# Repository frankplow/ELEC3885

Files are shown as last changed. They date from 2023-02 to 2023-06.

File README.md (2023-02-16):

# A robust and lightweight helmet-mounted safety camera for cycling
ELEC3885: Group Design Project, group 4 project at the University of Leeds.

The objective of this project is to design and produce a prototype for a camera to mount to the helmet of a cyclist, as well as a software suite for the analysis of footage and user documentation. The camera is intended as a safety device, for example for use in legal proceedings, rather than an 'action cam'. Because of this, it should be low-cost and should not require much effort by the user, for example charging, to use.

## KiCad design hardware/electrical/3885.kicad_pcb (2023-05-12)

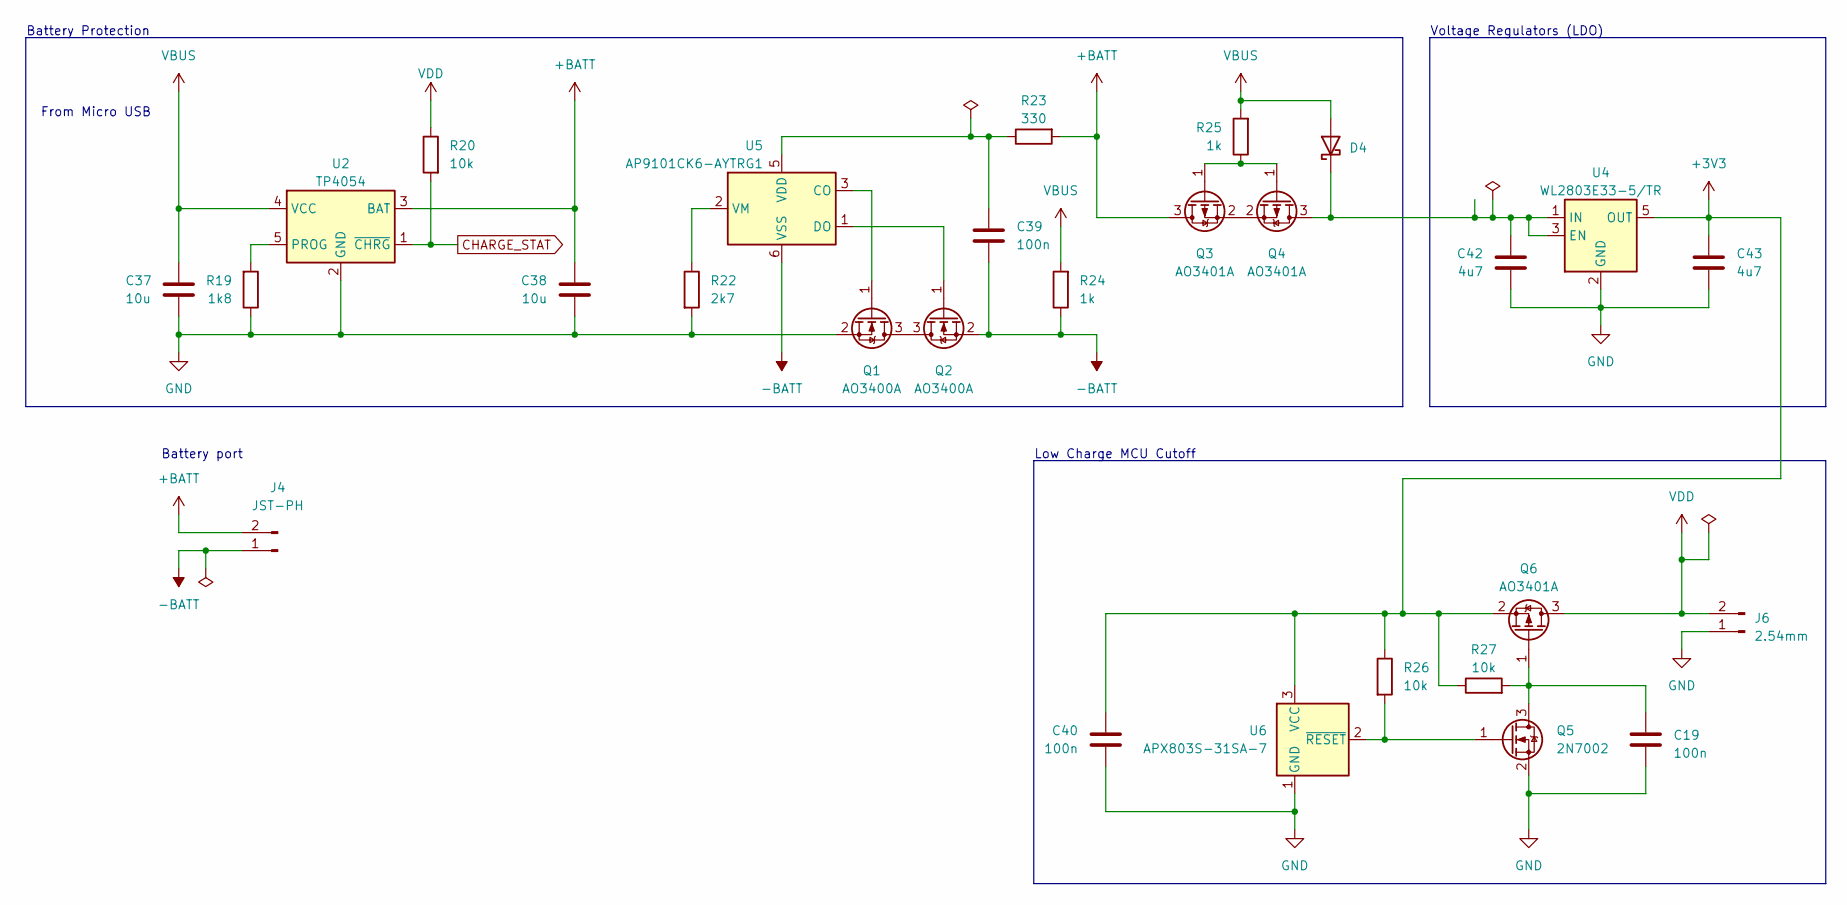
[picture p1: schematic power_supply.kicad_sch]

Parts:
C19, C39, C40: 100n; C_0402_1005Metric; Mfr. Part # CL05B104KO5NNNC; LCSC Part # C1525
C37, C38: 10u; C_0402_1005Metric; Mfr. Part # CL05A106MQ5NUNC; LCSC Part # C15525
C42, C43: 4u7; C_0402_1005Metric; Mfr. Part # CL05A475MP5NRNC; LCSC Part # C23733
D4: D_Schottky; D_SOD-323; Mfr. Part # 1N5819WS; LCSC Part # C191023
J4: JST-PH; JST_PH_S2B-PH-K_1x02_P2.00mm_Horizontal; Mfr. Part # S2B-PH-K-S(LF)(SN); LCSC Part # C173752
J6: 2.54mm; PinHeader_1x02_P2.54mm_Vertical
Q1, Q2: AO3400A; JLC_SOT-23; Mfr. Part # AO3400A; LCSC Part # C20917
Q3, Q4, Q6: AO3401A; JLC_SOT-23; Mfr. Part # AO3401A; LCSC Part # C15127
Q5: 2N7002; JLC_SOT-23; Mfr. Part # 2N7002; LCSC Part # C8545
R19: 1k8; R_0603_1608Metric; Mfr. Part # 0603WAF1801T5E; LCSC Part # C4177
R20, R26, R27: 10k; R_0402_1005Metric; Mfr. Part # 0402WGF1002TCE; LCSC Part # C25744
R22: 2k7; R_0603_1608Metric; Mfr. Part # 0603WAF2701T5E; LCSC Part # C13167
R23: 330; R_0402_1005Metric; Mfr. Part # 0402WGF3300TCE; LCSC Part # C25104
R24, R25: 1k; R_0402_1005Metric; Mfr. Part # 0402WGF1001TCE; LCSC Part # C11702
U2: TP4054; JLC_SOT-23-5; Mfr. Part # TP4054-42-SOT25R; LCSC Part # C32574
U4: WL2803E33-5/TR; JLC_SOT-23-5; Mfr. Part # WL2803E33-5/TR; LCSC Part # C192928
U5: AP9101CK6-AYTRG1; JLC_SOT-23-6; Mfr. Part # AP9101CK6-AYTRG1; LCSC Part # C507889
U6: APX803S-31SA-7; JLC_SOT-23; Mfr. Part # APX803S-31SA-7; LCSC Part # C129757

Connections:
+3V3: C40.1, C43.2, Q6.2 (S), R26.1, R27.1, U4.5 (OUT), U6.3 (VCC); also elsewhere on the board
+BATT: C38.2, J4.2, Q3.3 (D), R23.2, U2.3 (BAT)
-BATT: C39.1, J4.1, Q2.2 (S), R24.1, U5.6 (VSS)
CHARGE_STAT: R20.2, U2.1 (~CHRG); also elsewhere on the board
GND: C19.2, C37.2, C38.1, C40.2, C42.1, C43.1, J6.1, Q1.2 (S), Q5.2 (S), R19.1, R22.2, U2.2 (GND), U4.2 (GND), U6.1 (GND); also elsewhere on the board
unnamed: C42.2, D4.1 (K), Q4.3 (D), U4.1 (IN), U4.3 (EN)
unnamed: Q1.3 (D), Q2.3 (D)
unnamed: Q1.1 (G), U5.3 (CO)
unnamed: Q2.1 (G), U5.1 (DO)
unnamed: Q3.1 (G), Q4.1 (G), R25.1
unnamed: Q3.2 (S), Q4.2 (S)
unnamed: C19.1, Q5.3 (D), Q6.1 (G), R27.2
unnamed: Q5.1 (G), R26.2, U6.2 (~RESET)
unnamed: R19.2, U2.5 (PROG)
unnamed: C39.2, R23.1, U5.5 (VDD)
unnamed: R22.1, U5.2 (VM)
VBUS: C37.1, D4.2 (A), R24.2, R25.2, U2.4 (VCC); also elsewhere on the board
VDD: J6.2, Q6.3 (D), R20.1; also elsewhere on the board

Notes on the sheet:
Voltage Regulators (LDO)
Low Charge MCU Cutoff
From Micro USB
Battery Protection
Battery port

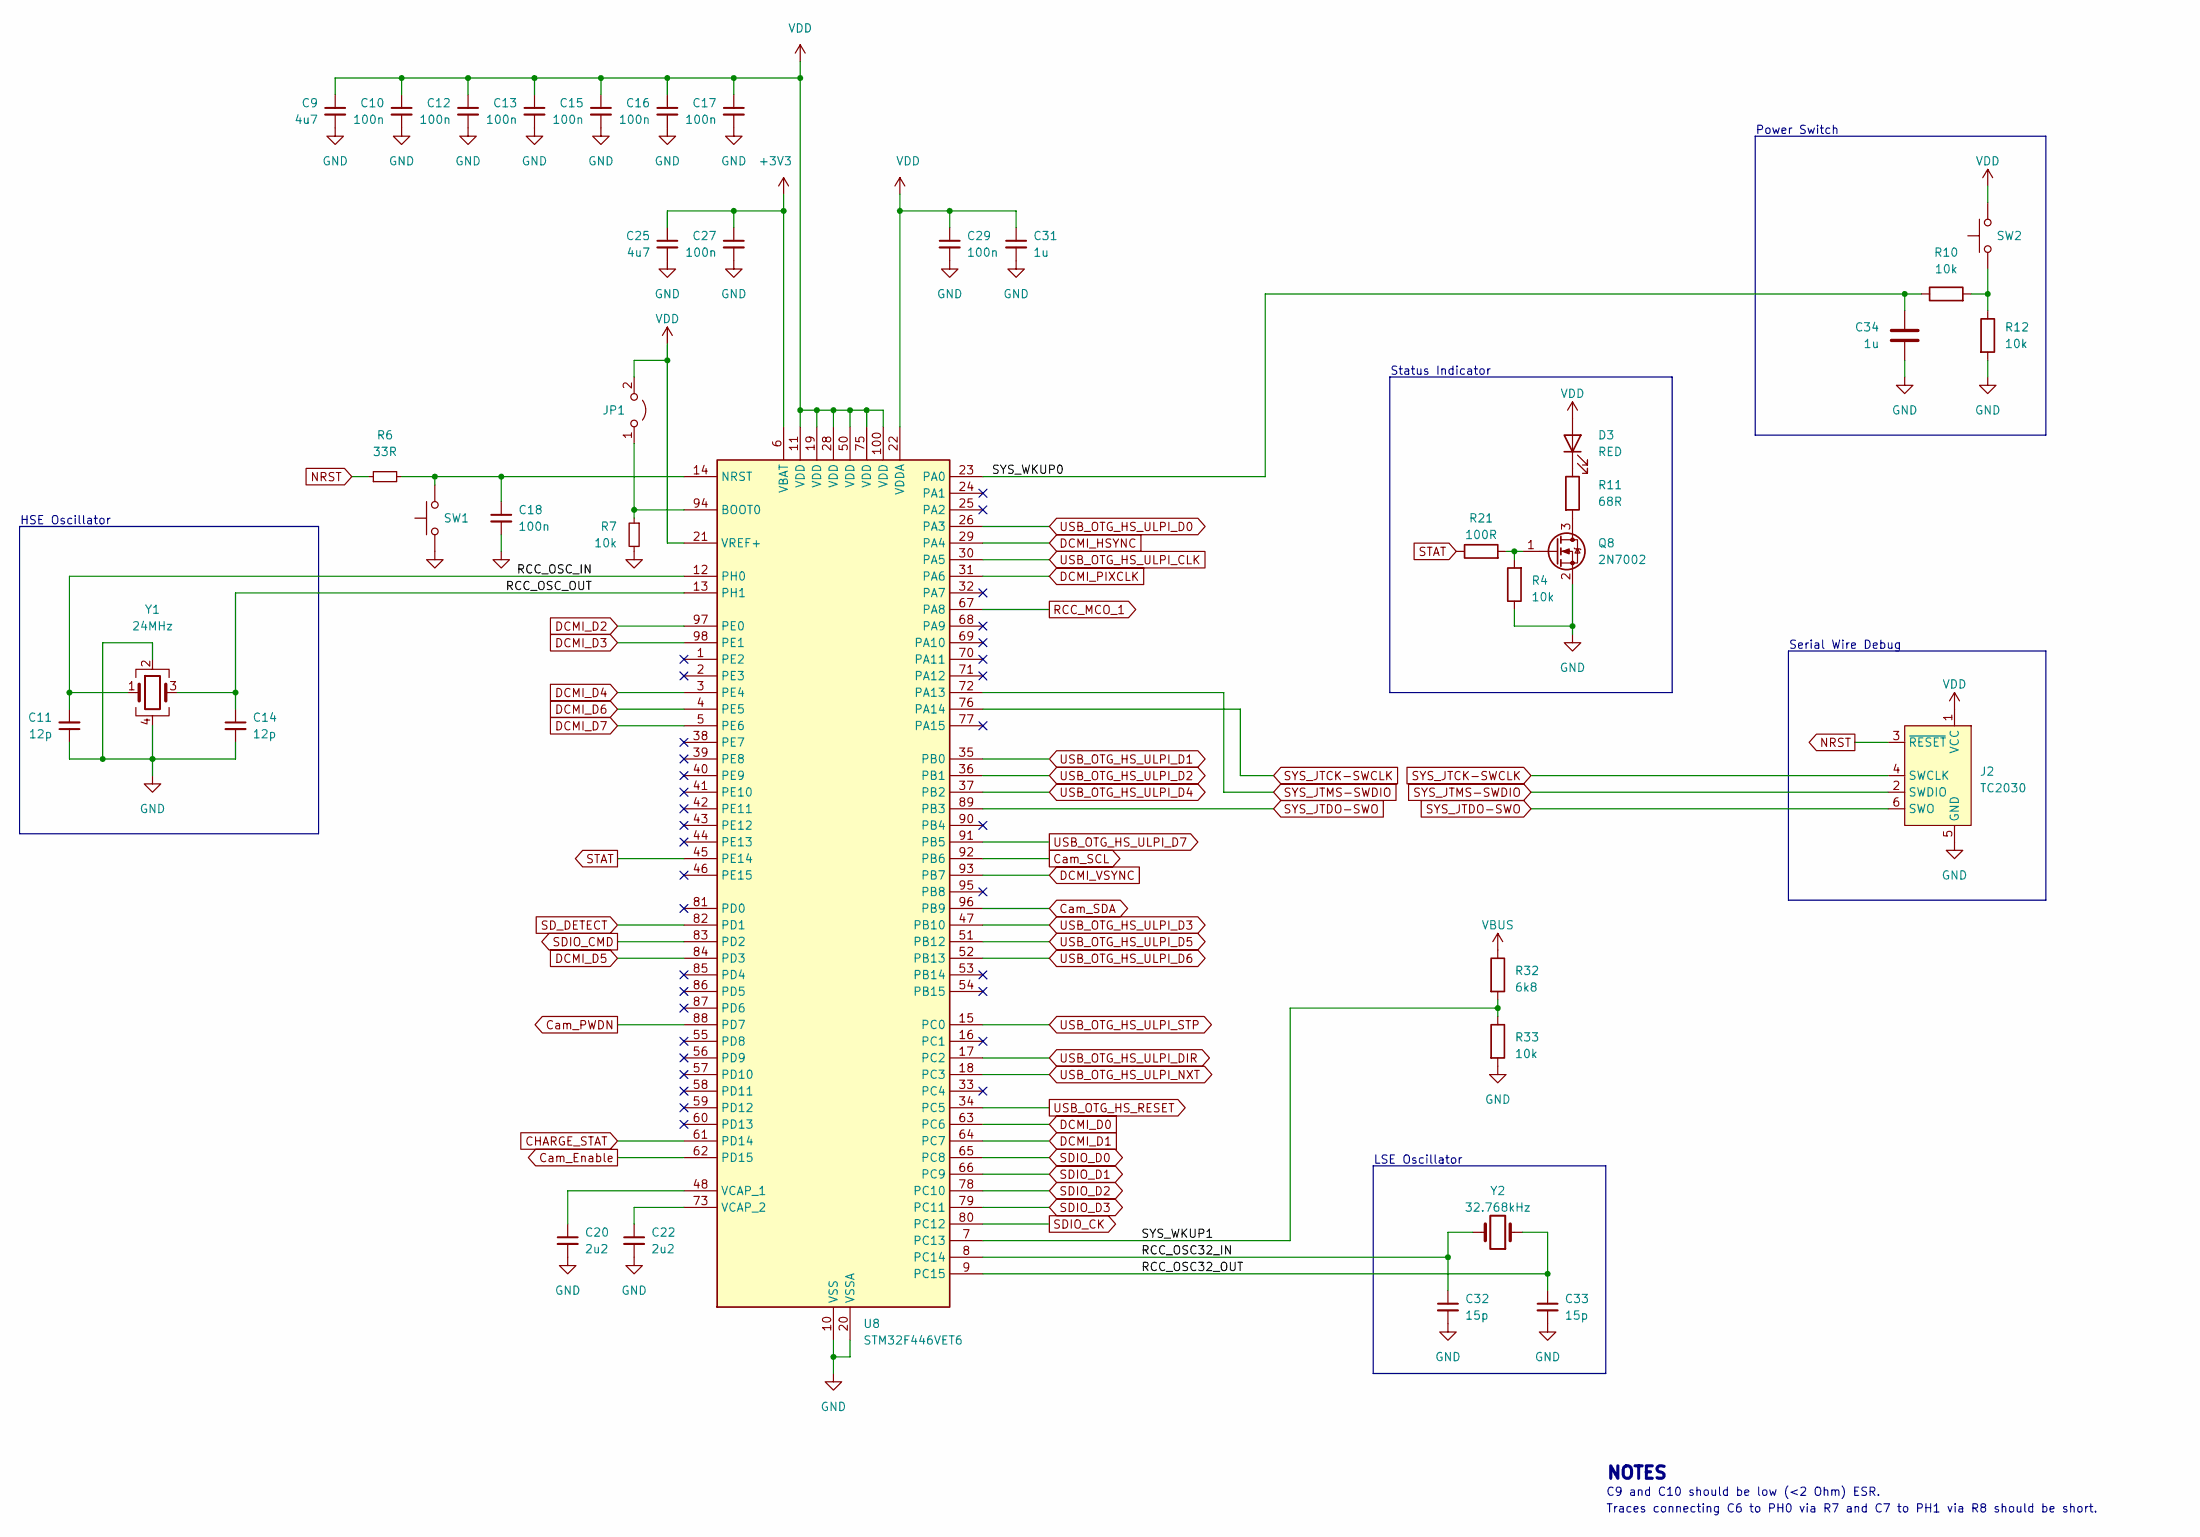
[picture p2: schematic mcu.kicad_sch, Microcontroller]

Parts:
C9, C25: 4u7; C_0402_1005Metric; Mfr. Part # CL05A475MP5NRNC; LCSC Part # C23733
C10, C12, C13, C15, C16, C17, C18, C27, C29: 100n; C_0402_1005Metric; Mfr. Part # CL05B104KO5NNNC; LCSC Part # C1525
C11, C14: 12p; C_0603_1608Metric; Mfr. Part # CL10C120JB8NNNC; LCSC Part # C38523
C20, C22: 2u2; C_0402_1005Metric; Mfr. Part # CL05A225MQ5NSNC; LCSC Part # C12530
C31, C34: 1u; C_0402_1005Metric; Mfr. Part # CL05A105KA5NQNC; LCSC Part # C52923
C32, C33: 15p; C_0603_1608Metric; Mfr. Part # CL10C150JB8NNNC; LCSC Part # C1644
D3: RED; Everlight_21-21S; Mfr. Part # 12-21SURC/S530-A3/TR8; LCSC Part # C131288
J2: TC2030; Tag-Connect_TC2030-IDC-FP_2x03_P1.27mm_Vertical
JP1: Jumper_2_Open; SolderJumper-2_P1.3mm_Open_Pad1.0x1.5mm
Q8: 2N7002; JLC_SOT-23; Mfr. Part # 2N7002; LCSC Part # C8545
R4: 10k; R_0402_1005Metric; Mfr. Part # 0402WGF1000TCE; LCSC Part # C25076
R6: 33R; R_0402_1005Metric; Mfr. Part # 0402WGF330JTCE; LCSC Part # C25105
R7, R10, R12, R33: 10k; R_0402_1005Metric; Mfr. Part # 0402WGF1002TCE; LCSC Part # C25744
R11: 68R; R_0603_1608Metric; Mfr. Part # 0603WAF680JT5E; LCSC Part # C27592
R21: 100R; R_0402_1005Metric; Mfr. Part # 0402WGF1000TCE; LCSC Part # C25076
R32: 6k8; R_0402_1005Metric; Mfr. Part # 0402WGF6801TCE; LCSC Part # C25917
SW1: TS-1187A-B-A-B; SW_SPST_XKB_TS-1187A; Mfr. Part # TS-1187A-B-A-B; LCSC Part # C318884
SW2: GT-TC018B-H0375-L1; G-Switch_GT-TC018; Mfr. Part # GT-TC018B-H0375-L1; LCSC Part # C2762970
U8: STM32F446VET6; JLC_LQFP-100_14x14mm_P0.5mm; Mfr. Part # STM32F446VET6; LCSC Part # C91929
Y1: 24MHz; Crystal_SMD_SeikoEpson_TSX3225-4Pin_3.2x2.5mm; Mfr. Part # X1E0000210129; LCSC Part # C255917
Y2: 32.768kHz; Crystal_SMD_3215-2Pin_3.2x1.5mm; Mfr. Part # Q13FC1350000400; LCSC Part # C32346

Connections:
+3V3: C25.1, C27.1, U8.6 (VBAT); also elsewhere on the board
/Microcontroller/RCC_OSC32_IN: C32.1, U8.8 (PC14), Y2.2
/Microcontroller/RCC_OSC32_OUT: C33.1, U8.9 (PC15), Y2.1
/Microcontroller/RCC_OSC_IN: C11.2, U8.12 (PH0), Y1.1
/Microcontroller/RCC_OSC_OUT: C14.1, U8.13 (PH1), Y1.3
/Microcontroller/SYS_WKUP0: C34.2, R10.1, U8.23 (PA0)
/Microcontroller/SYS_WKUP1: R32.2, R33.1, U8.7 (PC13)
CHARGE_STAT: U8.61 (PD14); also elsewhere on the board
Cam_Enable: U8.62 (PD15); also elsewhere on the board
Cam_PWDN: U8.88 (PD7); also elsewhere on the board
Cam_SCL: U8.92 (PB6); also elsewhere on the board
Cam_SDA: U8.96 (PB9); also elsewhere on the board
DCMI_D0: U8.63 (PC6); also elsewhere on the board
DCMI_D1: U8.64 (PC7); also elsewhere on the board
DCMI_D2: U8.97 (PE0); also elsewhere on the board
DCMI_D3: U8.98 (PE1); also elsewhere on the board
DCMI_D4: U8.3 (PE4); also elsewhere on the board
DCMI_D5: U8.84 (PD3); also elsewhere on the board
DCMI_D6: U8.4 (PE5); also elsewhere on the board
DCMI_D7: U8.5 (PE6); also elsewhere on the board
DCMI_HSYNC: U8.29 (PA4); also elsewhere on the board
DCMI_PIXCLK: U8.31 (PA6); also elsewhere on the board
DCMI_VSYNC: U8.93 (PB7); also elsewhere on the board
GND: C9.2, C10.2, C11.1, C12.2, C13.2, C14.2, C15.2, C16.2, C17.2, C18.2, C20.2, C22.2, C25.2, C27.2, C29.2, C31.2, C32.2, C33.2, C34.1, J2.5 (GND), Q8.2 (S), R4.1, R7.2, R12.2, R33.2, SW1.1, U8.10 (VSS), U8.20 (VSSA), U8.27 (VSS), U8.49 (VSS), U8.74 (VSS), U8.99 (VSS), Y1.2, Y1.4; also elsewhere on the board
NRST: J2.3 (~RESET), R6.1
unnamed: D3.1 (K), R11.1
unnamed: JP1.1 (A), R7.1, U8.94 (BOOT0)
unnamed: Q8.3 (D), R11.2
unnamed: Q8.1 (G), R4.2, R21.2
unnamed: R10.2, R12.1, SW2.1
unnamed: C18.1, R6.2, SW1.2, U8.14 (NRST)
unnamed: C20.1, U8.48 (VCAP_1)
unnamed: C22.1, U8.73 (VCAP_2)
RCC_MCO_1: U8.67 (PA8); also elsewhere on the board
SDIO_CK: U8.80 (PC12); also elsewhere on the board
SDIO_CMD: U8.83 (PD2); also elsewhere on the board
SDIO_D0: U8.65 (PC8); also elsewhere on the board
SDIO_D1: U8.66 (PC9); also elsewhere on the board
SDIO_D2: U8.78 (PC10); also elsewhere on the board
SDIO_D3: U8.79 (PC11); also elsewhere on the board
SD_DETECT: U8.82 (PD1); also elsewhere on the board
STAT: R21.1, U8.45 (PE14)
SYS_JTCK-SWCLK: J2.4 (SWCLK), U8.76 (PA14)
SYS_JTDO-SWO: J2.6 (SWO), U8.89 (PB3)
SYS_JTMS-SWDIO: J2.2 (SWDIO), U8.72 (PA13)
USB_OTG_HS_RESET: U8.34 (PC5); also elsewhere on the board
USB_OTG_HS_ULPI_CLK: U8.30 (PA5); also elsewhere on the board
USB_OTG_HS_ULPI_D0: U8.26 (PA3); also elsewhere on the board
USB_OTG_HS_ULPI_D1: U8.35 (PB0); also elsewhere on the board
USB_OTG_HS_ULPI_D2: U8.36 (PB1); also elsewhere on the board
USB_OTG_HS_ULPI_D3: U8.47 (PB10); also elsewhere on the board
USB_OTG_HS_ULPI_D4: U8.37 (PB2); also elsewhere on the board
USB_OTG_HS_ULPI_D5: U8.51 (PB12); also elsewhere on the board
USB_OTG_HS_ULPI_D6: U8.52 (PB13); also elsewhere on the board
USB_OTG_HS_ULPI_D7: U8.91 (PB5); also elsewhere on the board
USB_OTG_HS_ULPI_DIR: U8.17 (PC2); also elsewhere on the board
USB_OTG_HS_ULPI_NXT: U8.18 (PC3); also elsewhere on the board
USB_OTG_HS_ULPI_STP: U8.15 (PC0); also elsewhere on the board
VBUS: R32.1; also elsewhere on the board
VDD: C9.1, C10.1, C12.1, C13.1, C15.1, C16.1, C17.1, C29.1, C31.1, D3.2 (A), J2.1 (VCC), JP1.2 (B), SW2.2, U8.11 (VDD), U8.19 (VDD), U8.21 (VREF+), U8.22 (VDDA), U8.28 (VDD), U8.50 (VDD), U8.75 (VDD), U8.100 (VDD); also elsewhere on the board

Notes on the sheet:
C9 and C10 should be low (<2 Ohm) ESR.
Traces connecting C6 to PH0 via R7 and C7 to PH1 via R8 should be short.
LSE Oscillator
Serial Wire Debug
HSE Oscillator
Status Indicator
NOTES
Power Switch

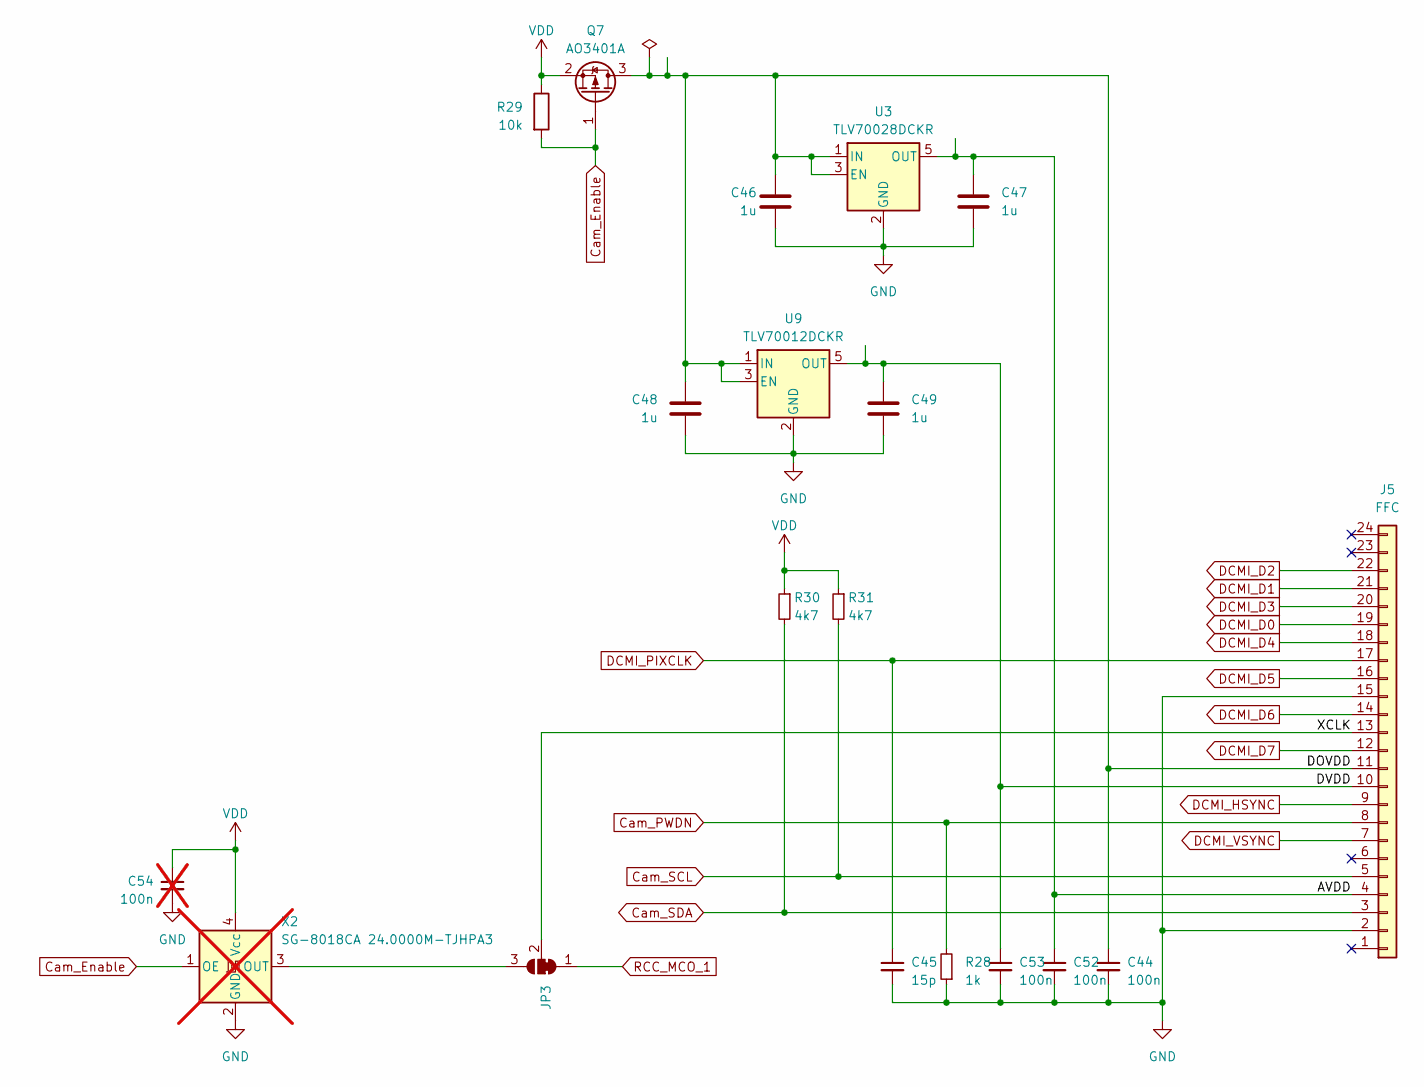
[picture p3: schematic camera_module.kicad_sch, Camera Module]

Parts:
C44, C52, C53: 100n; C_0402_1005Metric; Mfr. Part # CL05B104KO5NNNC; LCSC Part # C1525
C45: 15p; C_0603_1608Metric; Mfr. Part # CL10C150JB8NNNC; LCSC Part # C1644
C46, C47, C48, C49: 1u; C_0402_1005Metric; Mfr. Part # CL05A105KA5NQNC; LCSC Part # C52923
C54: 100n; C_0402_1005Metric; Mfr. Part # CL05B104KO5NNNC; LCSC Part # C1525; not fitted
J5: FFC; Jushuo_AFC07-S24ECA-00_1x24-1MP_P0.50_Horizontal; Mfr. Part # AFC07-S24ECA-00; LCSC Part # C262643
JP3: SolderJumper_3_Bridged12; SolderJumper-3_P1.3mm_Bridged12_Pad1.0x1.5mm
Q7: AO3401A; JLC_SOT-23; Mfr. Part # AO3401A; LCSC Part # C15127
R28: 1k; R_0402_1005Metric; Mfr. Part # 0402WGF1001TCE; LCSC Part # C11702
R29: 10k; R_0402_1005Metric; Mfr. Part # 0402WGF1002TCE; LCSC Part # C25744
R30, R31: 4k7; R_0402_1005Metric; Mfr. Part # 0402WGF4701TCE; LCSC Part # C25900
U3: TLV70028DCKR; JLC_SOT-353_SC-70-5; Mfr. Part # TLV70028DCKR; LCSC Part # C398921
U9: TLV70012DCKR; JLC_SOT-353_SC-70-5; Mfr. Part # TLV70012DCKR; LCSC Part # C96219
X2: SG-8018CA 24.0000M-TJHPA3; Oscillator_SMD_SeikoEpson_SG8002CA-4Pin_7.0x5.0mm_HandSolde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; not fitted

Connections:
/Camera Module/AVDD: C47.1, C52.1, J5.4, U3.5 (OUT)
/Camera Module/DOVDD: C44.1, C46.1, C48.1, J5.11, Q7.3 (D), U3.1 (IN), U3.3 (EN), U9.1 (IN), U9.3 (EN)
/Camera Module/DVDD: C49.1, C53.1, J5.10, U9.5 (OUT)
/Camera Module/XCLK: J5.13, JP3.2 (C)
Cam_Enable: Q7.1 (G), R29.2, X2.1 (OE); also elsewhere on the board
Cam_PWDN: J5.8, R28.2; also elsewhere on the board
Cam_SCL: J5.5, R31.2; also elsewhere on the board
Cam_SDA: J5.3, R30.2; also elsewhere on the board
DCMI_D0: J5.19; also elsewhere on the board
DCMI_D1: J5.21; also elsewhere on the board
DCMI_D2: J5.22; also elsewhere on the board
DCMI_D3: J5.20; also elsewhere on the board
DCMI_D4: J5.18; also elsewhere on the board
DCMI_D5: J5.16; also elsewhere on the board
DCMI_D6: J5.14; also elsewhere on the board
DCMI_D7: J5.12; also elsewhere on the board
DCMI_HSYNC: J5.9; also elsewhere on the board
DCMI_PIXCLK: C45.1, J5.17; also elsewhere on the board
DCMI_VSYNC: J5.7; also elsewhere on the board
GND: C44.2, C45.2, C46.2, C47.2, C48.2, C49.2, C52.2, C53.2, C54.2, J5.2, J5.15, R28.1, U3.2 (GND), U9.2 (GND), X2.2 (GND); also elsewhere on the board
unnamed: JP3.3 (B), X2.3 (OUT)
RCC_MCO_1: JP3.1 (A); also elsewhere on the board
VDD: C54.1, Q7.2 (S), R29.1, R30.1, R31.1, X2.4 (Vcc); also elsewhere on the board

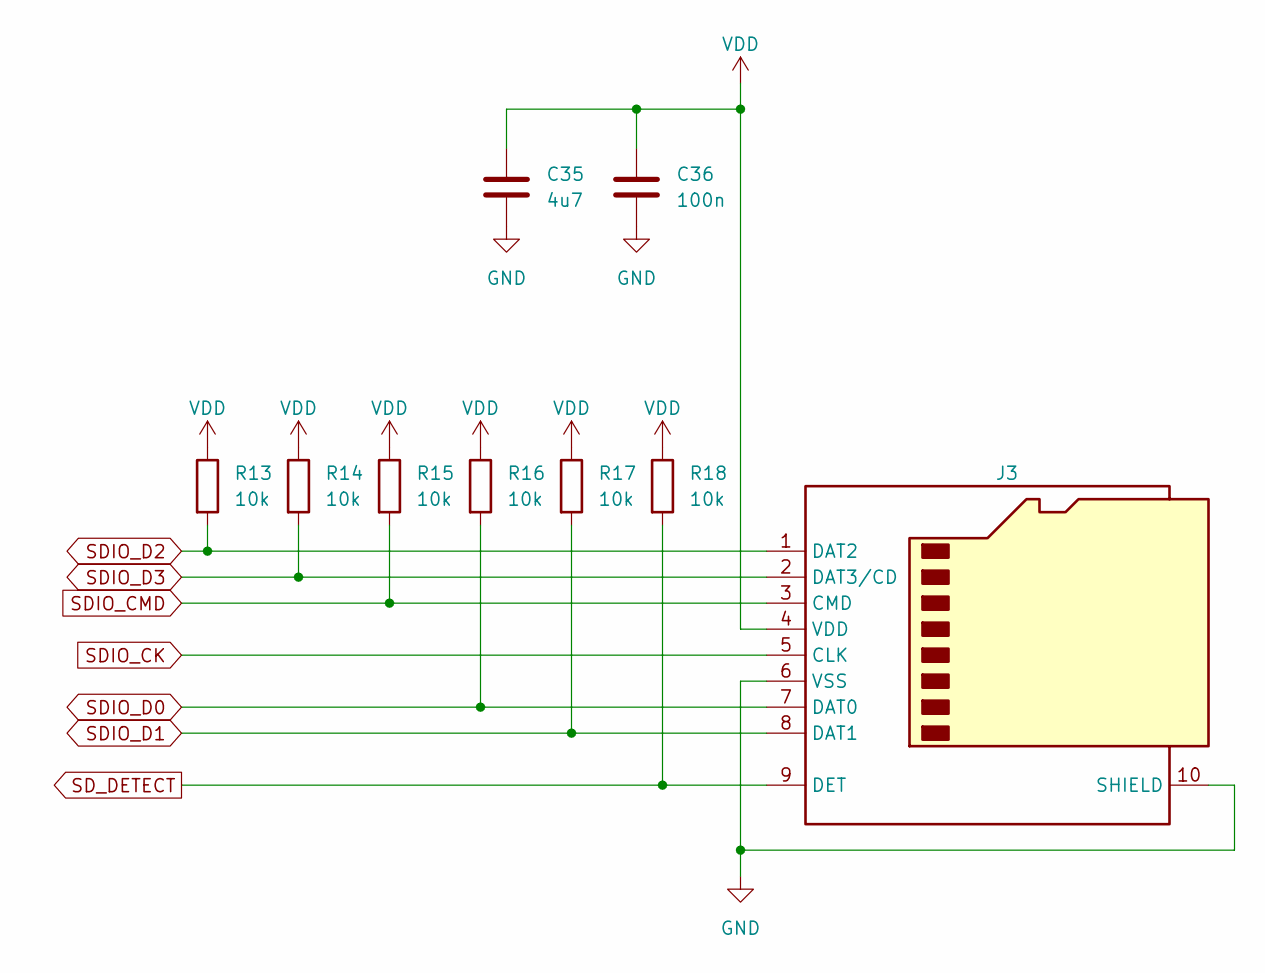
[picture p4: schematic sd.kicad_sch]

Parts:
C35: 4u7; C_0402_1005Metric; Mfr. Part # CL05A475MP5NRNC; LCSC Part # C23733
C36: 100n; C_0402_1005Metric; Mfr. Part # CL05B104KO5NNNC; LCSC Part # C1525
J3: Micro_SD_Card_Det1; microSD_HC_XKB_XKTF-N02-N; Mfr. Part # XKTF-N02-N; LCSC Part # C381084
R13, R14, R15, R16, R17, R18: 10k; R_0402_1005Metric; Mfr. Part # 0402WGF1002TCE; LCSC Part # C25744

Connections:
GND: C35.2, C36.2, J3.6 (VSS), J3.10 (SHIELD); also elsewhere on the board
SDIO_CK: J3.5 (CLK); also elsewhere on the board
SDIO_CMD: J3.3 (CMD), R15.2; also elsewhere on the board
SDIO_D0: J3.7 (DAT0), R16.2; also elsewhere on the board
SDIO_D1: J3.8 (DAT1), R17.2; also elsewhere on the board
SDIO_D2: J3.1 (DAT2), R13.2; also elsewhere on the board
SDIO_D3: J3.2 (DAT3/CD), R14.2; also elsewhere on the board
SD_DETECT: J3.9 (DET), R18.2; also elsewhere on the board
VDD: C35.1, C36.1, J3.4 (VDD), R13.1, R14.1, R15.1, R16.1, R17.1, R18.1; also elsewhere on the board

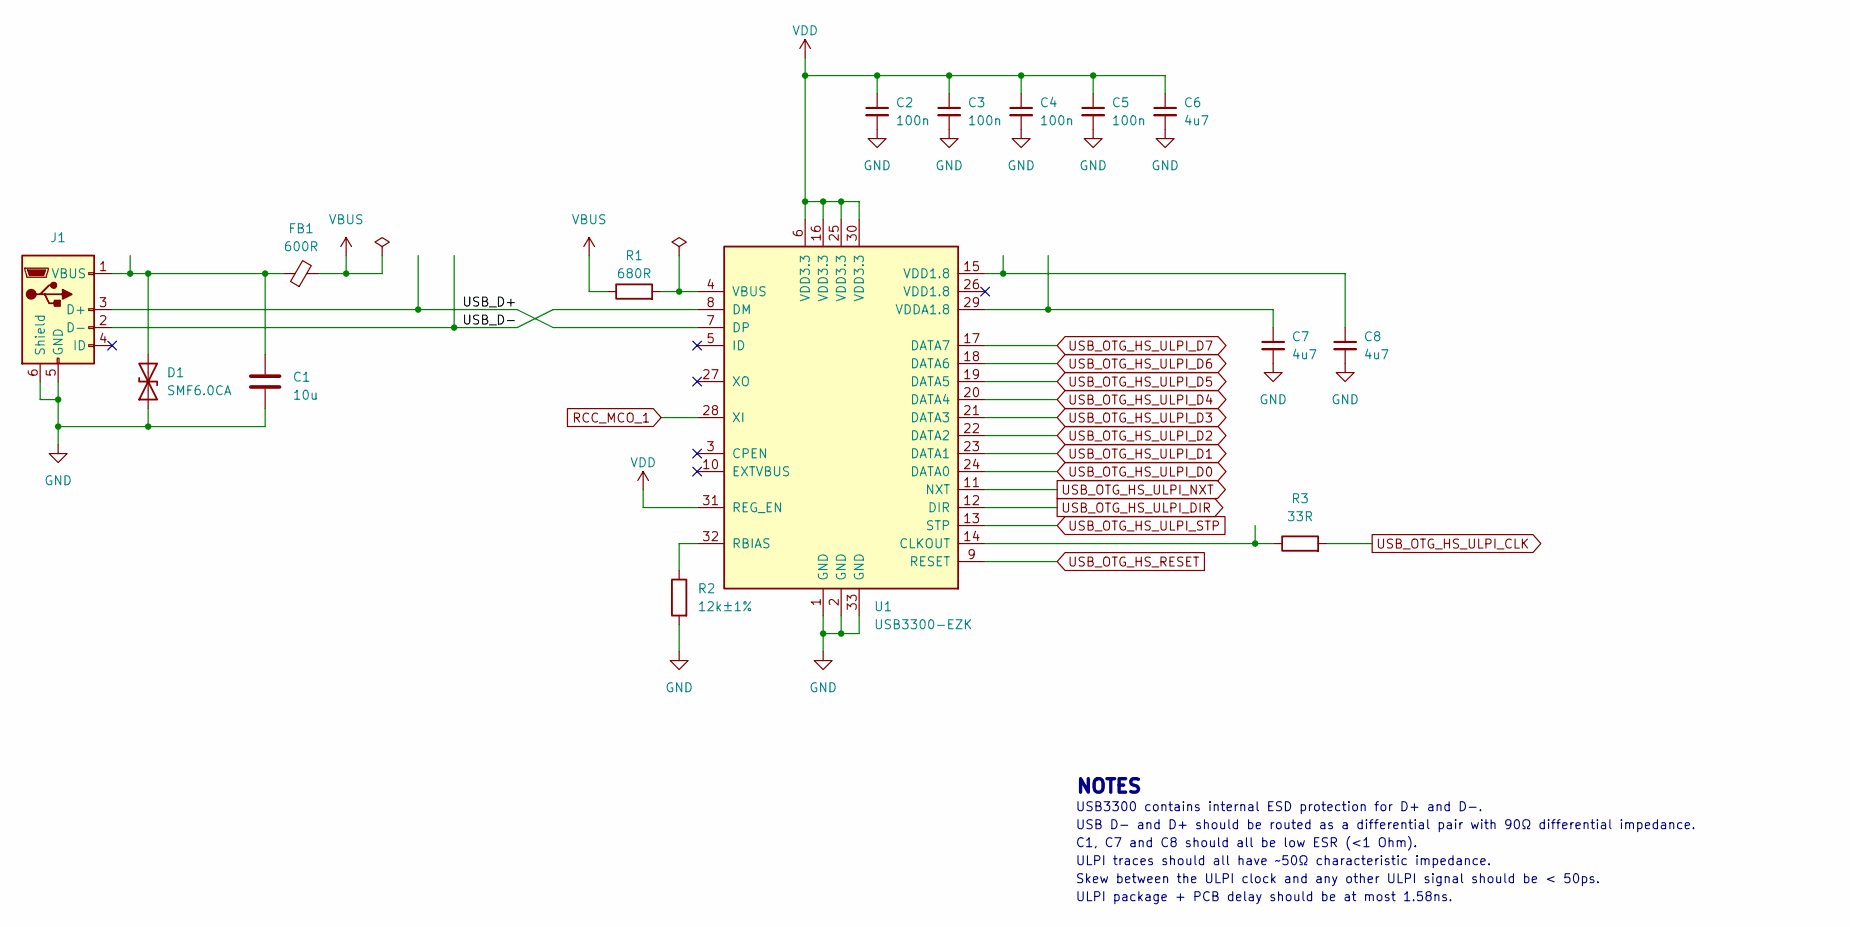
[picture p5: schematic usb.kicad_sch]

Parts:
C1: 10u; C_0402_1005Metric; Mfr. Part # CL05A106MQ5NUNC; LCSC Part # C15525
C2, C3, C4, C5: 100n; C_0402_1005Metric; Mfr. Part # CL05B104KO5NNNC; LCSC Part # C1525
C6, C7, C8: 4u7; C_0402_1005Metric; Mfr. Part # CL05A475MP5NRNC; LCSC Part # C23733
D1: SMF6.0CA; D_SOD-123F; Mfr. Part # SMF6.0CA; LCSC Part # C2990473
FB1: 600R; L_0805_2012Metric; Mfr. Part # GZ2012D601TF; LCSC Part # C1017
J1: USB_B_Micro; USB_Micro-B_Amphenol_10104110_Horizontal; Mfr. Part # 10104110-0001LF; LCSC Part # C2931352
R1: 680R; R_0402_1005Metric; Mfr. Part # 0402WGF6800TCE; LCSC Part # C25130
R2: 12k±1%; R_0402_1005Metric; Mfr. Part # 0402WGF1202TCE; LCSC Part # C25752
R3: 33R; R_0402_1005Metric; Mfr. Part # 0402WGF330JTCE; LCSC Part # C25105
U1: USB3300-EZK; JLC_QFN-32-1EP_5x5mm_P0.5mm_EP3.45x3.45mm; Mfr. Part # USB3300-EZK-TR; LCSC Part # C108383

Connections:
/USB/USB_D+: J1.3 (D+), U1.7 (DP)
/USB/USB_D-: J1.2 (D-), U1.8 (DM)
GND: C1.2, C2.2, C3.2, C4.2, C5.2, C6.2, C7.2, C8.2, D1.1 (A1), J1.5 (GND), J1.6 (Shield), R2.2, U1.1 (GND), U1.2 (GND), U1.33 (GND); also elsewhere on the board
unnamed: C8.1, U1.15 (VDD1.8)
unnamed: C1.1, D1.2 (A2), FB1.1, J1.1 (VBUS)
unnamed: R3.1, U1.14 (CLKOUT)
unnamed: R2.1, U1.32 (RBIAS)
unnamed: R1.2, U1.4 (VBUS)
unnamed: C7.1, U1.29 (VDDA1.8)
RCC_MCO_1: U1.28 (XI); also elsewhere on the board
USB_OTG_HS_RESET: U1.9 (RESET); also elsewhere on the board
USB_OTG_HS_ULPI_CLK: R3.2; also elsewhere on the board
USB_OTG_HS_ULPI_D0: U1.24 (DATA0); also elsewhere on the board
USB_OTG_HS_ULPI_D1: U1.23 (DATA1); also elsewhere on the board
USB_OTG_HS_ULPI_D2: U1.22 (DATA2); also elsewhere on the board
USB_OTG_HS_ULPI_D3: U1.21 (DATA3); also elsewhere on the board
USB_OTG_HS_ULPI_D4: U1.20 (DATA4); also elsewhere on the board
USB_OTG_HS_ULPI_D5: U1.19 (DATA5); also elsewhere on the board
USB_OTG_HS_ULPI_D6: U1.18 (DATA6); also elsewhere on the board
USB_OTG_HS_ULPI_D7: U1.17 (DATA7); also elsewhere on the board
USB_OTG_HS_ULPI_DIR: U1.12 (DIR); also elsewhere on the board
USB_OTG_HS_ULPI_NXT: U1.11 (NXT); also elsewhere on the board
USB_OTG_HS_ULPI_STP: U1.13 (STP); also elsewhere on the board
VBUS: FB1.2, R1.1; also elsewhere on the board
VDD: C2.1, C3.1, C4.1, C5.1, C6.1, U1.6 (VDD3.3), U1.16 (VDD3.3), U1.25 (VDD3.3), U1.30 (VDD3.3), U1.31 (REG_EN); also elsewhere on the board

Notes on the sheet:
USB D- and D+ should be routed as a differential pair with 90Ω differential impedance.
ULPI package + PCB delay should be at most 1.58ns.
NOTES
USB3300 contains internal ESD protection for D+ and D-.
C1, C7 and C8 should all be low ESR (<1 Ohm).
Skew between the ULPI clock and any other ULPI signal should be < 50ps.
ULPI traces should all have ~50Ω characteristic impedance.

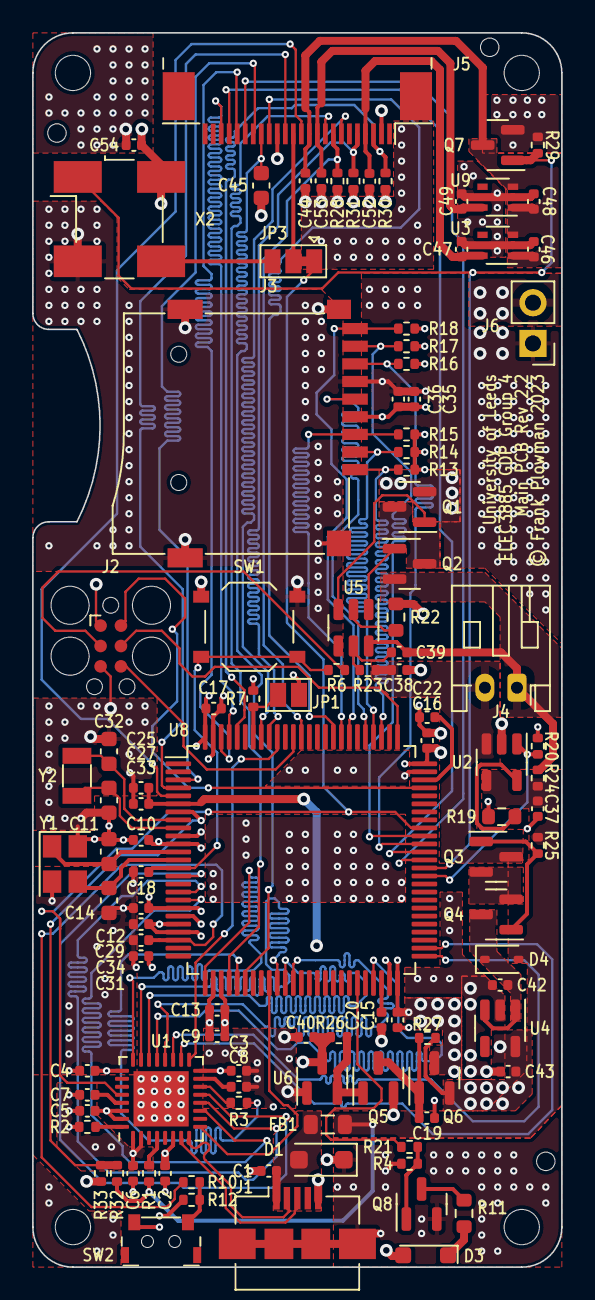
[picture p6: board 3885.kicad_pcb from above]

Board: 4 copper layers, 33.0 x 77.0 mm, 108 parts (0 on the bottom side), 86 nets.

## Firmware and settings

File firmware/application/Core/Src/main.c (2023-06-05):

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
/* Includes ------------------------------------------------------------------*/
#include "main.h"
#include "fatfs.h"

/* USER CODE BEGIN Includes */
#include "mutff.h"
#include "mutff_default.h"

#include "container.h"
#include "events.h"
#include "stm32f4xx_hal_gpio.h"
/* USER CODE END Includes */

DCMI_HandleTypeDef hdcmi;
DMA_HandleTypeDef hdma_dcmi;

I2C_HandleTypeDef hi2c1;

RTC_HandleTypeDef hrtc;

SD_HandleTypeDef hsd;
DMA_HandleTypeDef hdma_sdio;

/* USER CODE BEGIN PV */
FRESULT fatfs_err;
/* USER CODE END PV */

void SystemClock_Config(void);
static void MX_GPIO_Init(void);
static void MX_DMA_Init(void);
static void MX_DCMI_Init(void);
static void MX_I2C1_Init(void);
static void MX_RTC_Init(void);
static void MX_SDIO_SD_Init(void);
/* USER CODE BEGIN 0 */
struct Cam_config default_settings =  {
        .img_format = FMT_JPEG,
        .x_res = 800, //DVP timings need to be change for hi res
        .y_res = 600,
        .FPS = 20, //Can be 8, 15, 20, 23, 25, or 30. Setting to 9 == default PLL configuration (usually ~10FPS)
        .jpeg_comp_ratio = 12, // 1- 63 lower = better quality
        .v_flipped = OV5640_MIRROR_Y,
};

void turn_off() {
  BSP_CAMERA_Stop();

  // Close file
  fatfs_err = f_close(&SDFile);
  if (fatfs_err != FR_OK) {
    exit(fatfs_err);
  }

  HAL_GPIO_WritePin(STAT_GPIO_Port, STAT_Pin, GPIO_PIN_RESET);
  HAL_PWR_EnterSTANDBYMode();
}

void HAL_GPIO_EXTI_Callback(uint16_t GPIO_Pin) {
  switch (GPIO_Pin) {
    case WKUP_Pin:
      push_event_queue((Event) {
        .type = PowerOff,
        .data = NULL,
      });
      break;
    default:
      break;
  }
}

void handle_event(Event event) {
    switch (event.type) {
      case DCMIFrameComplete: {
          const DCMIFrameCompleteEventData event_data =
                  *((DCMIFrameCompleteEventData*) event.data);
          container_on_dcmi_frame_complete(event_data);
          free(event.data);
          break;
      }
      case DCMIDataReady: {
          const DCMIDataReadyEventData event_data =
                  *((DCMIDataReadyEventData*) event.data);
          container_on_dcmi_data_ready(event_data);
          free(event.data);
          break;
      }
      case DCMIVSync: {
          break;
      }
      case PowerOff: {
          turn_off();
          break;
      }
      case USBPluggedIn: {
          break;
      }
      default:
          Error_Handler();
          break;
    }
}

/* USER CODE END 0 */

/**
  * @brief  The application entry point.
  * @retval int
  */
int main(void)
{
  /* MCU Configuration--------------------------------------------------------*/

  /* Reset of all peripherals, Initializes the Flash interface and the Systick. */
  HAL_Init();

  /* USER CODE BEGIN Init */
  /* HAL_PWR_EnableWakeUpPin(PWR_WAKEUP_PIN1); */
  /* USER CODE END Init */

  /* Configure the system clock */
  SystemClock_Config();

  /* Initialize all configured peripherals */
  MX_GPIO_Init();
  MX_DMA_Init();
  MX_DCMI_Init();
  MX_I2C1_Init();
  MX_RTC_Init();
  MX_SDIO_SD_Init();
  MX_FATFS_Init();
  /* USER CODE BEGIN 2 */
  printf("Main Init\n");
  HAL_GPIO_WritePin(STAT_GPIO_Port, STAT_Pin, GPIO_PIN_SET);

  // Mount filesystem
  fatfs_err = f_mount(&SDFatFS, SDPath, 1);
  if (fatfs_err != FR_OK) {
    printf("failed to mount card, code: %i.\n", fatfs_err);
    if (fatfs_err != FR_NOT_READY) {
      printf("exiting.\n");
      exit(fatfs_err);
    }
    printf("continuing.\n");
  }

  // Open file
  fatfs_err = f_open(&SDFile, "3885.mp4", FA_WRITE | FA_CREATE_ALWAYS);
  if (fatfs_err != FR_OK) {
    printf("failed to open file, code: %i.\n", fatfs_err);
    printf("exiting.\n");
    exit(fatfs_err);
  }

  container_set_frame_rate(default_settings.FPS);
  container_set_resolution(default_settings.x_res, default_settings.y_res);
  container_set_format(MuTFF_FOURCC('j', 'p', 'e', 'g'));
  container_init(&SDFile);

  if (CAM_Init(default_settings.img_format,
           default_settings.x_res,
           default_settings.y_res,
           default_settings.FPS,
           default_settings.jpeg_comp_ratio,
           default_settings.v_flipped,
           default_settings.light_mode,
           default_settings.saturation,
           default_settings.contrast) != CAMERA_OK) {
    exit(1);
  }

  BSP_CAMERA_ContinuousStart();

  /* USER CODE END 2 */

  /* Infinite loop */
  /* USER CODE BEGIN WHILE */
  while (1)
  {
    // Sleep until an interrupt occurs
    HAL_SuspendTick();
    HAL_PWR_EnterSLEEPMode(PWR_MAINREGULATOR_ON, PWR_SLEEPENTRY_WFI);
    HAL_ResumeTick();
    /* USER CODE END WHILE */

    /* USER CODE BEGIN 3 */
    // Handle any events produced by the interrupt
    Event event;
    while (pop_event_queue(&event)) {
      handle_event(event);
    }
    /* USER CODE BEGIN 3 */
  }
  /* USER CODE END 3 */
}

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


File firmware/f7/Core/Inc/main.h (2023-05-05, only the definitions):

#define LCD_B0_Pin GPIO_PIN_4
#define LCD_B0_GPIO_Port GPIOE
#define OTG_HS_OverCurrent_Pin GPIO_PIN_3
#define OTG_HS_OverCurrent_GPIO_Port GPIOE
#define QSPI_D2_Pin GPIO_PIN_2
#define QSPI_D2_GPIO_Port GPIOE
#define RMII_TXD1_Pin GPIO_PIN_14
#define RMII_TXD1_GPIO_Port GPIOG
#define FMC_NBL1_Pin GPIO_PIN_1
#define FMC_NBL1_GPIO_Port GPIOE
#define FMC_NBL0_Pin GPIO_PIN_0
#define FMC_NBL0_GPIO_Port GPIOE
#define ARDUINO_SCL_D15_Pin GPIO_PIN_8
#define ARDUINO_SCL_D15_GPIO_Port GPIOB
#define ULPI_D7_Pin GPIO_PIN_5
#define ULPI_D7_GPIO_Port GPIOB
#define ARDUINO_PWM_D3_Pin GPIO_PIN_4
#define ARDUINO_PWM_D3_GPIO_Port GPIOB
#define SWO_Pin GPIO_PIN_3
#define SWO_GPIO_Port GPIOB
#define SPDIF_RX0_Pin GPIO_PIN_7
#define SPDIF_RX0_GPIO_Port GPIOD
#define SDMMC_CK_Pin GPIO_PIN_12
#define SDMMC_CK_GPIO_Port GPIOC
#define ARDUINO_PWM_D9_Pin GPIO_PIN_15
#define ARDUINO_PWM_D9_GPIO_Port GPIOA
#define SWCLK_Pin GPIO_PIN_14
#define SWCLK_GPIO_Port GPIOA
#define SWDIO_Pin GPIO_PIN_13
#define SWDIO_GPIO_Port GPIOA
#define DCMI_D6_Pin GPIO_PIN_5
#define DCMI_D6_GPIO_Port GPIOE
#define DCMI_D7_Pin GPIO_PIN_6
#define DCMI_D7_GPIO_Port GPIOE
#define RMII_TXD0_Pin GPIO_PIN_13
#define RMII_TXD0_GPIO_Port GPIOG
#define ARDUINO_SDA_D14_Pin GPIO_PIN_9
#define ARDUINO_SDA_D14_GPIO_Port GPIOB
#define VCP_RX_Pin GPIO_PIN_7
#define VCP_RX_GPIO_Port GPIOB
#define QSPI_NCS_Pin GPIO_PIN_6
#define QSPI_NCS_GPIO_Port GPIOB
#define FMC_SDNCAS_Pin GPIO_PIN_15
#define FMC_SDNCAS_GPIO_Port GPIOG
#define RMII_TX_EN_Pin GPIO_PIN_11
#define RMII_TX_EN_GPIO_Port GPIOG
#define LCD_B1_Pin GPIO_PIN_13
#define LCD_B1_GPIO_Port GPIOJ
#define OTG_FS_VBUS_Pin GPIO_PIN_12
#define OTG_FS_VBUS_GPIO_Port GPIOJ
#define Audio_INT_Pin GPIO_PIN_6
#define Audio_INT_GPIO_Port GPIOD
#define FMC_D2_Pin GPIO_PIN_0
#define FMC_D2_GPIO_Port GPIOD
#define SDMMC_D3_Pin GPIO_PIN_11
#define SDMMC_D3_GPIO_Port GPIOC
#define SDMMC_D2_Pin GPIO_PIN_10
#define SDMMC_D2_GPIO_Port GPIOC
#define OTG_FS_P_Pin GPIO_PIN_12
#define OTG_FS_P_GPIO_Port GPIOA
#define NC1_Pin GPIO_PIN_8
#define NC1_GPIO_Port GPIOI
#define SAI2_MCLKA_Pin GPIO_PIN_4
#define SAI2_MCLKA_GPIO_Port GPIOI
#define LCD_DE_Pin GPIO_PIN_7
#define LCD_DE_GPIO_Port GPIOK
#define LCD_B7_Pin GPIO_PIN_6
#define LCD_B7_GPIO_Port GPIOK
#define LCD_B6_Pin GPIO_PIN_5
#define LCD_B6_GPIO_Port GPIOK
#define LCD_B4_Pin GPIO_PIN_12
#define LCD_B4_GPIO_Port GPIOG
#define SAI2_SDB_Pin GPIO_PIN_10
#define SAI2_SDB_GPIO_Port GPIOG
#define LCD_B2_Pin GPIO_PIN_14
#define LCD_B2_GPIO_Port GPIOJ
#define OTG_FS_PowerSwitchOn_Pin GPIO_PIN_5
#define OTG_FS_PowerSwitchOn_GPIO_Port GPIOD
#define DCMI_D5_Pin GPIO_PIN_3
#define DCMI_D5_GPIO_Port GPIOD
#define FMC_D3_Pin GPIO_PIN_1
#define FMC_D3_GPIO_Port GPIOD
#define ARDUINO_D7_Pin GPIO_PIN_3
#define ARDUINO_D7_GPIO_Port GPIOI
#define ARDUINO_D8_Pin GPIO_PIN_2
#define ARDUINO_D8_GPIO_Port GPIOI
#define OTG_FS_N_Pin GPIO_PIN_11
#define OTG_FS_N_GPIO_Port GPIOA
#define uSD_Detect_Pin GPIO_PIN_13
#define uSD_Detect_GPIO_Port GPIOC
#define FMC_A0_Pin GPIO_PIN_0
#define FMC_A0_GPIO_Port GPIOF
#define SAI2_SCKA_Pin GPIO_PIN_5
#define SAI2_SCKA_GPIO_Port GPIOI
#define SAI2_FSA_Pin GPIO_PIN_7
#define SAI2_FSA_GPIO_Port GPIOI
#define LCD_HSYNC_Pin GPIO_PIN_10
#define LCD_HSYNC_GPIO_Port GPIOI
#define SAI2_SDA_Pin GPIO_PIN_6
#define SAI2_SDA_GPIO_Port GPIOI
#define LCD_B5_Pin GPIO_PIN_4
#define LCD_B5_GPIO_Port GPIOK
#define LCD_BL_CTRL_Pin GPIO_PIN_3
#define LCD_BL_CTRL_GPIO_Port GPIOK
#define DCMI_VSYNC_Pin GPIO_PIN_9
#define DCMI_VSYNC_GPIO_Port GPIOG
#define LCD_B3_Pin GPIO_PIN_15
#define LCD_B3_GPIO_Port GPIOJ
#define OTG_FS_OverCurrent_Pin GPIO_PIN_4
#define OTG_FS_OverCurrent_GPIO_Port GPIOD
#define SDMMC_D0_Pin GPIO_PIN_2
#define SDMMC_D0_GPIO_Port GPIOD
#define TP3_Pin GPIO_PIN_15
#define TP3_GPIO_Port GPIOH
#define ARDUINO_SCK_D13_Pin GPIO_PIN_1
#define ARDUINO_SCK_D13_GPIO_Port GPIOI
#define OTG_FS_ID_Pin GPIO_PIN_10
#define OTG_FS_ID_GPIO_Port GPIOA
#define RCC_OSC32_IN_Pin GPIO_PIN_14
#define RCC_OSC32_IN_GPIO_Port GPIOC
#define FMC_A1_Pin GPIO_PIN_1
#define FMC_A1_GPIO_Port GPIOF
#define LCD_DISP_Pin GPIO_PIN_12
#define LCD_DISP_GPIO_Port GPIOI
#define LCD_VSYNC_Pin GPIO_PIN_9
#define LCD_VSYNC_GPIO_Port GPIOI
#define DCMI_PWR_EN_Pin GPIO_PIN_13
#define DCMI_PWR_EN_GPIO_Port GPIOH
#define DCMI_D4_Pin GPIO_PIN_14
#define DCMI_D4_GPIO_Port GPIOH
#define ARDUINO_PWM_CS_D5_Pin GPIO_PIN_0
#define ARDUINO_PWM_CS_D5_GPIO_Port GPIOI
#define VCP_TX_Pin GPIO_PIN_9
#define VCP_TX_GPIO_Port GPIOA
#define RCC_OSC32_OUT_Pin GPIO_PIN_15
#define RCC_OSC32_OUT_GPIO_Port GPIOC
#define LCD_G6_Pin GPIO_PIN_1
#define LCD_G6_GPIO_Port GPIOK
#define LCD_G7_Pin GPIO_PIN_2
#define LCD_G7_GPIO_Port GPIOK
#define ARDUINO_PWM_D10_Pin GPIO_PIN_8
#define ARDUINO_PWM_D10_GPIO_Port GPIOA
#define OSC_25M_Pin GPIO_PIN_0
#define OSC_25M_GPIO_Port GPIOH
#define FMC_A2_Pin GPIO_PIN_2
#define FMC_A2_GPIO_Port GPIOF
#define LCD_INT_Pin GPIO_PIN_13
#define LCD_INT_GPIO_Port GPIOI
#define LCD_R0_Pin GPIO_PIN_15
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

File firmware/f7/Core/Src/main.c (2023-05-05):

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
/* Includes ------------------------------------------------------------------*/
#include "main.h"
#include "fatfs.h"

/* USER CODE BEGIN Includes */
#include <stdbool.h>

#include "mutff.h"
#include "mutff_default.h"

#include "container.h"
#include "events.h"
#include "stm32f7xx_hal.h"
/* USER CODE END Includes */


DCMI_HandleTypeDef hdcmi;
DMA_HandleTypeDef hdma_dcmi;

I2C_HandleTypeDef hi2c1;

SD_HandleTypeDef hsd1;
DMA_HandleTypeDef hdma_sdmmc1;

TIM_HandleTypeDef htim3;

PCD_HandleTypeDef hpcd_USB_OTG_HS;

/* USER CODE BEGIN PV */
static FRESULT fatfs_err;
/* USER CODE END PV */

void SystemClock_Config(void);
static void MX_GPIO_Init(void);
static void MX_DMA_Init(void);
static void MX_I2C1_Init(void);
static void MX_DCMI_Init(void);
static void MX_USB_OTG_HS_PCD_Init(void);
static void MX_SDMMC1_SD_Init(void);
static void MX_TIM3_Init(void);
/* USER CODE BEGIN PFP */

/// @brief Dispatches an event to the relevant handler
/// @param event The event to dispatch
void handle_event(Event event);
/* USER CODE END PFP */

/* USER CODE BEGIN 0 */
void handle_event(Event event) {
    switch (event.type) {
      case DCMIFrameComplete: {
          //printf("[%lu] Handling DCMIFrameComplete\n", HAL_GetTick());
          const DCMIFrameCompleteEventData event_data =
                  *((DCMIFrameCompleteEventData*) event.data);
          container_on_dcmi_frame_complete(event_data);
          free(event.data);
          //printf("[%lu] Done handling DCMIFrameComplete\n", HAL_GetTick());
          break;
      }
      case DCMIDataReady: {
          //printf("[%lu] Handling DCMIDataReady\n", HAL_GetTick());
          const DCMIDataReadyEventData event_data =
                  *((DCMIDataReadyEventData*) event.data);
          container_on_dcmi_data_ready(event_data);
          //printf("[%lu] Done handling DCMIDataReady\n", HAL_GetTick());
          free(event.data);
          break;
      }
      case DCMIVSync: {
          break;
      }
      case PowerOff: {
          break;
      }
      case USBPluggedIn: {
          break;
      }
      default:
          Error_Handler();
          break;
    }
}

struct Cam_config default_settings =  {
        .img_format = FMT_JPEG,
        .x_res = 800, //DVP timings need to be change for hi res
        .y_res = 600,
        .FPS = 25, //Can be 8, 15, 20, 23, 25, or 30. Setting to 9 == default PLL configuration (usually ~10FPS)
        .jpeg_comp_ratio = 12 // 1- 63 lower = better quality
};

/* USER CODE END 0 */

/**
  * @brief  The application entry point.
  * @retval int
  */
int main(void)
{
  /* MCU Configuration--------------------------------------------------------*/

  /* Reset of all peripherals, Initializes the Flash interface and the Systick. */
  HAL_Init();

  /* Configure the system clock */
  SystemClock_Config();

  /* Initialize all configured peripherals */
  MX_GPIO_Init();
  MX_DMA_Init();
  MX_I2C1_Init();
  MX_DCMI_Init();
  MX_USB_OTG_HS_PCD_Init();
  MX_FATFS_Init();
  MX_SDMMC1_SD_Init();
  MX_TIM3_Init();
  /* USER CODE BEGIN 2 */
//start FPS counter
    if (HAL_TIM_Base_Start_IT(&htim3) != HAL_OK)
  {
    /* Starting Error */
    Error_Handler();
  }
  //Mount filesystem
  fatfs_err = f_mount(&SDFatFS, SDPath, 1);
  if (fatfs_err != FR_OK) {
    printf("failed to mount card, code: %i.\n", fatfs_err);
    if (fatfs_err != FR_NOT_READY) {
      printf("exiting.\n");
      exit(fatfs_err);
    }
    printf("continuing.\n");
  }

  // Open file
  fatfs_err = f_open(&SDFile, "3885.mp4", FA_WRITE | FA_CREATE_ALWAYS);
  if (fatfs_err != FR_OK) {
    printf("failed to open file, code: %i.\n", fatfs_err);
    printf("exiting.\n");
    exit(fatfs_err);
  }

  container_set_frame_rate(default_settings.FPS);
  container_set_resolution(default_settings.x_res, default_settings.y_res);
  container_set_format(MuTFF_FOURCC('j', 'p', 'e', 'g'));
  container_init(&SDFile);

  CAM_Init(default_settings.img_format,
           default_settings.x_res,
           default_settings.y_res,
           default_settings.FPS,
           default_settings.jpeg_comp_ratio);

  BSP_CAMERA_ContinuousStart();
  /* USER CODE END 2 */

  /* Infinite loop */
  /* USER CODE BEGIN WHILE */
  while (1)
  {
    // Sleep until an interrupt occurs
   
    HAL_SuspendTick();
    HAL_PWR_EnterSLEEPMode(PWR_MAINREGULATOR_ON, PWR_SLEEPENTRY_WFI);
    HAL_ResumeTick();
    /* USER CODE END WHILE */

    /* USER CODE BEGIN 3 */
    // Handle any events produced by the interrupt
    Event event;
    while (pop_event_queue(&event)) {
      handle_event(event);
    }
  }
  /* USER CODE END 3 */
}

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


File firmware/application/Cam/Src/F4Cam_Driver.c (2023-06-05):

#include "F4Cam_Driver.h"


#include "camera_I2C.h"
// #include "events.h"
// #include "stm32f7xx_hal.h"
// #include "stm32f7xx_hal_dcmi.h"
// #include "stm32f7xx_hal_gpio.h"

#define OV5640

char cam_fb[CAM_FB_SIZE];  // __attribute__ ((section (".sdram"), aligned (4)));

uint8_t frames_per_second = 0;

bool capture_data = false;

DCMI_HandleTypeDef hDcmiHandler;

void DCMI_DMA_TRANSFER_HALF_COMPLETE(DMA_HandleTypeDef *hdma);
void DCMI_DMA_TRANSFER_COMPLETE(DMA_HandleTypeDef *hdma);
static void DCMI_DMAError(DMA_HandleTypeDef *hdma);

#ifdef OV5640
Camera_StatusTypeDef CAM_Init(uint8_t format, uint16_t x_res, uint16_t y_res,
                              uint8_t FPS, uint8_t jpeg_comp_ratio,
                              OV5640_Mirror mirror, OV5640_LightMode lightmode, OV5640_Saturation saturation, OV5640_Contrast contrast) {
  DCMI_HandleTypeDef *phdcmi;

  /* Get the DCMI handle structure */
  phdcmi = &hDcmiHandler;

  /*** Configures the DCMI to interface with the camera module ***/
  /* DCMI configuration */
  phdcmi->Init.CaptureRate = DCMI_CR_ALL_FRAME;
  phdcmi->Init.HSPolarity = DCMI_HSPOLARITY_HIGH;
  phdcmi->Init.SynchroMode = DCMI_SYNCHRO_HARDWARE;
  phdcmi->Init.VSPolarity = DCMI_VSPOLARITY_HIGH;
  phdcmi->Init.ExtendedDataMode = DCMI_EXTEND_DATA_8B;
  phdcmi->Init.PCKPolarity = DCMI_PCKPOLARITY_RISING;
  if (format == FMT_JPEG) {
    phdcmi->Init.JPEGMode = DCMI_JPEG_ENABLE;
  }
  phdcmi->Instance = DCMI;

  BSP_CAMERA_PwrDown();
  BSP_CAMERA_PwrUp();
  HAL_Delay(1000);
  
  const uint16_t id = ov5640_ReadID();
  if (id != OV5640_ID) {
    printf("Read ID incorrect\n");
    return CAMERA_NOT_SUPPORTED;
  }
  printf("Read ID correct\n");

  // Set image format
  switch (format) {
    case FMT_JPEG: {
      ov5640_Init_JPEG(x_res, y_res, PACKET_SIZE, PACKET_COUNT,
                       jpeg_comp_ratio);
      if (FPS != 9) {
        OV5640_SetPCLK(FPS);
      }
      OV5640_Set_Comp_Ratio(jpeg_comp_ratio);
      break;
    }
    case FMT_RGB565: {
      ov5640_Init_RGB565(x_res, y_res);
      break;
    }
    default: {
      break;
    }
  }

  OV5640_MirrorFlipConfig(mirror);
  OV5640_SetLightMode(lightmode);
  OV5640_SetSaturation(saturation);
  OV5640_SetContrast(contrast);

  /* DCMI Initialization */
  BSP_CAMERA_MspInit(&hDcmiHandler, NULL);
  HAL_DCMI_Init(phdcmi);
  HAL_DCMI_DisableCROP(phdcmi);

  return CAMERA_OK;
}
#endif

uint8_t BSP_CAMERA_DeInit(void) {
  hDcmiHandler.Instance = DCMI;

  HAL_DCMI_DeInit(&hDcmiHandler);
  BSP_CAMERA_MspDeInit(&hDcmiHandler, NULL);
  return CAMERA_OK;
}

void BSP_CAMERA_ContinuousStart() {
  // Wait for first VSYNC
  while (!(HAL_GPIO_ReadPin(GPIOB, GPIO_PIN_7))) {
  }

  capture_data = true;
  HAL_DCMI_Start_DMA2(&hDcmiHandler, DCMI_MODE_CONTINUOUS, (uintptr_t)cam_fb,
                      CAM_FB_SIZE);
}

void BSP_CAMERA_Suspend(void) {
  HAL_DCMI_Suspend(&hDcmiHandler);
}

void BSP_CAMERA_Resume(void) {
  HAL_DCMI_Resume(&hDcmiHandler);
}

uint8_t BSP_CAMERA_Stop(void) {
  uint8_t status = CAMERA_ERROR;

  if (HAL_DCMI_Stop(&hDcmiHandler) == HAL_OK) {
    status = CAMERA_OK;
  }

  BSP_CAMERA_PwrDown();

  return status;
}

void BSP_CAMERA_PwrUp(void) {
  GPIO_InitTypeDef gpio_init_structure;

  /* Enable GPIO clock */
  __HAL_RCC_GPIOD_CLK_ENABLE();

  /*** Configure the GPIO ***/
  /* Configure DCMI GPIO as alternate function */
  gpio_init_structure.Pin = GPIO_PIN_7;
  gpio_init_structure.Mode = GPIO_MODE_OUTPUT_PP;
  gpio_init_structure.Pull = GPIO_NOPULL;
  gpio_init_structure.Speed = GPIO_SPEED_HIGH;
  HAL_GPIO_Init(GPIOD, &gpio_init_structure);

  /* De-assert the camera POWER_DOWN pin (active high) */ 
  HAL_GPIO_WritePin(GPIOD, GPIO_PIN_7, GPIO_PIN_RESET);

  HAL_Delay(5); /* POWER_DOWN de-asserted during 3ms */
}

void BSP_CAMERA_PwrDown(void) {
  GPIO_InitTypeDef gpio_init_structure;

  /* Enable GPIO clock */
  __HAL_RCC_GPIOD_CLK_ENABLE();

  /*** Configure the GPIO ***/
  /* Configure DCMI GPIO as alternate function */
  gpio_init_structure.Pin = GPIO_PIN_7;
  gpio_init_structure.Mode = GPIO_MODE_OUTPUT_PP;
  gpio_init_structure.Pull = GPIO_NOPULL;
  gpio_init_structure.Speed = GPIO_SPEED_HIGH;
  HAL_GPIO_Init(GPIOD, &gpio_init_structure);

  /* Assert the camera POWER_DOWN pin (active high) */
  //HAL_GPIO_WritePin(GPIOD, GPIO_PIN_15, GPIO_PIN_SET);

  HAL_GPIO_WritePin(GPIOD, GPIO_PIN_7, GPIO_PIN_SET);

  //HAL_GPIO_TogglePin(STAT_GPIO_Port, STAT_Pin);

}

__weak void BSP_CAMERA_MspInit(DCMI_HandleTypeDef *hdcmi, void *Params) {
  static DMA_HandleTypeDef hdma_handler;
  GPIO_InitTypeDef gpio_init_structure;

  /*** Enable peripherals and GPIO clocks ***/
  /* Enable DCMI clock */
  __HAL_RCC_DCMI_CLK_ENABLE();

  /* Enable DMA2 clock */
  __HAL_RCC_DMA2_CLK_ENABLE();

  /* Enable GPIO clocks   A B C D E for DCMI GPIO */
  __HAL_RCC_GPIOA_CLK_ENABLE();
  __HAL_RCC_GPIOB_CLK_ENABLE();
  __HAL_RCC_GPIOC_CLK_ENABLE();
  __HAL_RCC_GPIOD_CLK_ENABLE();
  __HAL_RCC_GPIOE_CLK_ENABLE();

  /*** Configure the GPIO ***/
  /* Configure DCMI GPIO as alternate function */

  //PINS A4 HYSNC A6 PIXCLK
  //A4 - HYSNC, A6 - PCLK
  gpio_init_structure.Pin = GPIO_PIN_4 | GPIO_PIN_6;
  gpio_init_structure.Mode = GPIO_MODE_AF_PP;
  gpio_init_structure.Pull = GPIO_PULLUP;
  gpio_init_structure.Speed = GPIO_SPEED_HIGH;
  gpio_init_structure.Alternate = GPIO_AF13_DCMI;
  HAL_GPIO_Init(GPIOA, &gpio_init_structure); //

  //PINS G9 --> VSYNC
  //VSYNC : PB7
  gpio_init_structure.Pin = GPIO_PIN_7;
  gpio_init_structure.Mode = GPIO_MODE_AF_PP;
  gpio_init_structure.Pull = GPIO_PULLUP;
  gpio_init_structure.Speed = GPIO_SPEED_HIGH;
  gpio_init_structure.Alternate = GPIO_AF13_DCMI;
  HAL_GPIO_Init(GPIOB, &gpio_init_structure); //

  //C6, C7  --> DATA0, DATA 1
  gpio_init_structure.Pin = GPIO_PIN_6 | GPIO_PIN_7;
  gpio_init_structure.Mode = GPIO_MODE_AF_PP;
  gpio_init_structure.Pull = GPIO_PULLUP;
  gpio_init_structure.Speed = GPIO_SPEED_HIGH;
  gpio_init_structure.Alternate = GPIO_AF13_DCMI;
  HAL_GPIO_Init(GPIOC, &gpio_init_structure);

  //D3 --> DATA 5
  gpio_init_structure.Pin = GPIO_PIN_3;
  gpio_init_structure.Mode = GPIO_MODE_AF_PP;
  gpio_init_structure.Pull = GPIO_PULLUP;
  gpio_init_structure.Speed = GPIO_SPEED_HIGH;
  gpio_init_structure.Alternate = GPIO_AF13_DCMI;
  HAL_GPIO_Init(GPIOD, &gpio_init_structure);


  //E0,1,4,5,6 --> DATA 2:7
  gpio_init_structure.Pin = GPIO_PIN_0 | GPIO_PIN_1 | GPIO_PIN_4 | GPIO_PIN_5 | GPIO_PIN_6;
  gpio_init_structure.Mode = GPIO_MODE_AF_PP;
  gpio_init_structure.Pull = GPIO_PULLUP;
  gpio_init_structure.Speed = GPIO_SPEED_HIGH;
  gpio_init_structure.Alternate = GPIO_AF13_DCMI;
  HAL_GPIO_Init(GPIOE, &gpio_init_structure);
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

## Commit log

2023-02-16 Create KiCad project
    [3885.kicad_pcb, 3885.kicad_sch]
2023-02-16 Set up KiCad design rules for JLCPCB capabilities
    [3885.kicad_pcb]
2023-02-17 Hardware schematic hierarchy
    [3885.kicad_sch, charging.kicad_sch, mcu.kicad_sch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]
2023-02-17 initial commit of power module schematic and PCB
    [3885.kicad_pcb, power_supply.kicad_sch]
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2023-02-17 Power schematic style changes * Use power ports over global labels where possible * Replace 3.3V connector with test points * Make all component labels upright
    [3885.kicad_sch, power_supply.kicad_sch]
2023-02-17 grouped test points
    [3885.kicad_sch, power_supply.kicad_sch]
2023-02-18 Mark R1 as TBD and add value to J3
    [3885.kicad_sch, power_supply.kicad_sch]
2023-02-19 Remove SW1 and D1
    [3885.kicad_sch, power_supply.kicad_sch]
2023-02-19 Add USB VBUS filtering
    [3885.kicad_sch, power_supply.kicad_sch]
2023-02-19 Add microcontroller and pinout to schematic
    [mcu.kicad_sch]
2023-02-19 Add HSE oscillator circuit
    [3885.kicad_sch, mcu.kicad_sch]
2023-02-19 Add serial wire debug connection and boot selection circuitry to schematic
    [3885.kicad_sch, mcu.kicad_sch, power_supply.kicad_sch]
2023-02-19 Add status LED, power switch and charge detction
    [3885.kicad_sch, mcu.kicad_sch]
2023-02-20 PCB updated
    JTC connector added; test points added; Schottky diode changed to SMD
    [3885.kicad_pcb, 3885.kicad_sch, power_supply.kicad_sch]
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2023-02-20 Add LSE oscillator
    [3885.kicad_sch, mcu.kicad_sch]
2023-02-21 Move power switch to WKUP0 pin and make it positive logic
    [mcu.kicad_sch, power_supply.kicad_sch]
2023-02-21 Fix typo - PE4 should be DCMI_D4
    [mcu.kicad_sch]
2023-02-22 Add VDD cutoff circuitry
    [3885.kicad_sch, mcu.kicad_sch, power_supply.kicad_sch]
2023-02-22 corrected mistake in the original schematic
    Source and drain of P-channel MOSFET Q3 were flipped
    [power_supply.kicad_sch]
2023-02-27 Add netclasses
    [3885.kicad_sch]
2023-02-27 Add USB PHY IC
    [3885.kicad_sch, mcu.kicad_sch, power_supply.kicad_sch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]
2023-02-27 Update STM32CubeMX configuration to match schematic and fix ERC
    [3885.kicad_sch, mcu.kicad_sch, power_supply.kicad_sch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]
2023-02-27 USB signal integrity tweaks. * Replace DNP capacitor at USB with 4.7µF per USB specification * Replace 0R ferrite bead with 100Ω@100MHz * Connect shield to ground * Replace 0R VBUS sense resistor wit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
    [3885.kicad_sch, mcu.kicad_sch, power_supply.kicad_sch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]
2023-02-27 Minor USB schematic tweaks * Remove extra 100nF decoupling capacitor * Add notes on routing ULPI traces * Schematic formatting tweaks
    [3885.kicad_sch, usb.kicad_sch]
2023-02-27 Add SD card to schematic (#5)
    [3885.kicad_sch, mcu.kicad_sch, sd.kicad_sch]
2023-02-27 Fix schematic formatting (#6)
    * Fix schematic formatting
    * Clear and re-annotate to fix ERC
    [3885.kicad_sch, mcu.kicad_sch, power_supply.kicad_sch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]
2023-03-03 Camera Module Schematic (#7)
    * Camera Module Schematic
    * Add camera module sheet to schematic hierarchy
    * Connect camera module to MCU and fix ERC
    * Replace LFSPXO018541 with SG-210STF
    ---------
    [3885.kicad_sch, camera_module.kicad_sch, mcu.kicad_sch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]
2023-03-12 Remove FMC peripheral
    [camera_module.kicad_sch, mcu.kicad_sch, power_supply.kicad_sch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]
2023-03-12 Remove ESD protection from SWD connector
    [mcu.kicad_sch]
2023-03-12 Update footprints to KiCad 7.0 versions
    [camera_module.kicad_sch, mcu.kicad_sch, power_supply.kicad_sch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]
2023-03-12 Update camera connector schematic * Connect PWDN and PCLK to MCU * Replace SG-210STF (2520) with SG-8018CA (7050) * Mark X2 and C54 as DNP * Replace regulators with TLV700*
    [camera_module.kicad_sch, mcu.kicad_sch]
2023-03-12 Use VDD in place of +3.3V more extensively
    [camera_module.kicad_sch, mcu.kicad_sch, sd.kicad_sch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]
2023-03-12 Replace SW2 with a momentary switch
    [mcu.kicad_sch]
2023-03-12 Connect USB VBUS to WKUP1
    [mcu.kicad_sch]
2023-03-12 Change microcontroller to STM32F446VET6
    [mcu.kicad_sch]
2023-03-12 updated charger IC
    note on charge status signal:
    LOW when charging
    HIGH when charge cycle completed or USB not connected
    [power_supply.kicad_sch, usb.kicad_sch]
2023-03-12 Replace TP4054 symbol with custom symbol
    [mcu.kicad_sch, power_supply.kicad_sch, usb.kicad_sch]
2023-03-12 Replace 3.3V regulator with AMS1117-3.3 and use more readily available capacitor values
    [power_supply.kicad_sch]
2023-03-12 Revert "Replace 3.3V regulator with AMS1117-3.3 and use more readily available capacitor values"
    This reverts commit 29fecb9214ea02ba74fbe5bb5a2b4ebe43046313.
    [power_supply.kicad_sch]
2023-03-12 Replace 3.3V regulator with WL2803E
    [power_supply.kicad_sch]
2023-03-12 Reinstate netclass assignments
    [mcu.kicad_sch, usb.kicad_sch]
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2023-03-21 Fix off-by-one errors in event queue access
    [main.c]
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2023-03-30 Bolster VBUS filtering
    [usb.kicad_sch]
2023-03-30 Replace Y1 and Y2 with generic crystals
    [mcu.kicad_sch]
2023-03-30 Use netclass labels to assign netclasses to unlabelled nets
    [camera_module.kicad_sch, power_supply.kicad_sch, usb.kicad_sch]
2023-03-30 changed R23 value
    100 -> 330
    [power_supply.kicad_sch]
2023-03-30 Component selection
    [camera_module.kicad_sch, mcu.kicad_sch, power_supply.kicad_sch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]
2023-03-30 Add Everlight 12-21S footprint
    [mcu.kicad_sch]
2023-03-30 Add XKTF-N02-N footprint
    [mcu.kicad_sch, sd.kicad_sch, usb.kicad_sch]
2023-03-30 Add Jushou AFC07-S24ECA-00 footprint and reverse J5 numbering to match camera cable
    [camera_module.kicad_sch, mcu.kicad_sch, power_supply.kicad_sch]
2023-03-30 Add footprint for XKB TS-1187A
    [mcu.kicad_sch]
2023-03-30 Add manufacturing design rules
    [3885.kicad_pcb]
2023-03-30 Add mechanical constraints
    [3885.kicad_pcb]
2023-03-30 Change R23 part no.
    [power_supply.kicad_sch]
2023-03-30 Add custom rules for ULPI and USB skew constraints
    [3885.kicad_pcb, usb.kicad_sch]
2023-03-30 Component placement
    [3885.kicad_pcb]
2023-03-30 Route ULPI and power supply
    [3885.kicad_pcb, mcu.kicad_sch, usb.kicad_sch]
2023-03-30 Revise power supply
    [3885.kicad_pcb, mcu.kicad_sch, power_supply.kicad_sch]
2023-03-30 Remove components from in front of the JST connector
    [3885.kicad_pcb]
2023-03-30 PCB Rev 2.0
    [3885.kicad_pcb, mcu.kicad_sch]
2023-03-30 Fix silkscreen DRC errors
    [3885.kicad_pcb]
2023-03-30 Add chamfering to DCMI corners
    [3885.kicad_pcb]
2023-03-30 Configure export for JLCPCB
    [3885.kicad_pcb, camera_module.kicad_sch]
2023-03-30 Add JLCPCB assembly tooling holes
    [3885.kicad_pcb]
2023-03-30 Replace user switch with GT-TC018B-H0375-L1
    [3885.kicad_pcb, mcu.kicad_sch]
2023-03-30 DNP all through-hole parts
    [3885.kicad_pcb]
2023-03-30 Implement James' recommendations
    * Move R22 GND via out of -BATT fill
    * Remove TP1 from schematic
    * Remove TP2 from schematic
    * Remove JP2 from schematic
    [3885.kicad_pcb, power_supply.kicad_sch]
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2023-04-14 fixed size calculations for frame sizes
    [F7Cam_Driver.c, f7.ioc, main.c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]
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2023-04-15 Endianness-independent host-to-network-order conversions
    Previous implementation inverted endianness. This is okay
    on a typical little-endian system however ARM Cortex cores
    can be configured as big-endian. New code will convert to
    big endian from either host endianness.
    [Camera_I2C.c]
2023-04-16 Implemented 640 x 480 at 15FPS
    --> Getting a Huffman table decode error
    --> Video mostly alright but glitches ~ every 5 seconds
    [F7Cam_Driver.c, main.c, ov5640_driver.c]
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2023-04-16 Fix DataReady event for large buffers
    [F7Cam_Driver.c]
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2023-04-24 Implemented working camera driver, fixed JPEG size
    [F7Cam_Driver.c, f7.ioc, main.c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]
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2023-04-25 Fix SD duplicated bytes error
    [f7.ioc]
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2023-05-04 Add JLCPCB order number location
    [3885.kicad_pcb]
2023-05-04 Adjust part positions and rotations to match JLCPCB
    [3885.kicad_pcb]
2023-05-04 Final PCB tweaks
    [3885.kicad_pcb]
2023-05-04 Fixed I2c, tested communication with image sensor
    [Camera_I2C.c, F4Cam_Driver.c, application.ioc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]
2023-05-05 Fix memory access error
    [main.c]
2023-05-05 Add camera flip function
    [F4Cam_Driver.c, main.c, main.h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]
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2023-05-12 Make design rules more conservative
    [3885.kicad_pcb]
2023-05-12 Increase clearances to pass stricter DRC
    [3885.kicad_pcb, power_supply.kicad_sch]
2023-05-12 Connect U5 VSS to -BATT instead of GND
    [3885.kicad_pcb, 3885.kicad_sch, camera_module.kicad_sch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]
2023-05-12 Lower NPTH clearance to 0.254mm
    [3885.kicad_pcb]
2023-05-12 SCL and SDA pulled-up not pulled-down
    [3885.kicad_pcb, camera_module.kicad_sch]
2023-05-12 Fix STAT LED drive circuit
    [3885.kicad_pcb, mcu.kicad_sch]
2023-05-12 Replace USB connector with SMD part
    [3885.kicad_pcb, usb.kicad_sch]
2023-05-12 Add J6 to directly power with 3.3V
    [3885.kicad_pcb, power_supply.kicad_sch]
2023-05-12 Fix power button footprint
    [3885.kicad_pcb, mcu.kicad_sch]
2023-05-12 Add capacitor to voltage supervisor circuit
    [3885.kicad_pcb, 3885.kicad_sch, camera_module.kicad_sch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]
2023-05-12 JLCPCB position and rotation adjustments
    [3885.kicad_pcb, camera_module.kicad_sch, mcu.kicad_sch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]
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

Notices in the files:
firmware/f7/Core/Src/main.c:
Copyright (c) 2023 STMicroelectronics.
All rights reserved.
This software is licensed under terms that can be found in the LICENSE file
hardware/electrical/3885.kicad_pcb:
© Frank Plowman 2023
